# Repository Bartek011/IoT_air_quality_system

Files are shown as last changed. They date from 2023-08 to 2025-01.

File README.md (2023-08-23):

real

# Introduction
The aim of this thesis was to develop a system responsible for the control of air quality with particular emphasis on the measurement of concentrations of volatile organic compounds [VOC](https://www.epa.gov/indoor-air-quality-iaq/what-are-volatile-organic-compounds-vocs) and atmospheric particulate matter [PM](https://www.epa.gov/pm-pollution/particulate-matter-pm-basics).
System also provide measurment of temperature, humidity and atmospheric pressure. The data is available on the local server as measurment dashboard created in Grafana.
User can also receive notification about dangerour level of pollution via discord server

# Flow chart

real

# PCB

real

# Housing

real

# Grafana
Grafana was used to create dashbord with every available measurement data.

real
real
real

# Thesis
Thesis was published in polish on [Base of Knowledge Warsaw Univesity of Technology](https://repo.pw.edu.pl/info/bachelor/WUTc83da9b0bee349f29c8757139889ff39/Record%2Bdetails%2B%25E2%2580%2593%2BEngineer%2527s%2B%2B%2BBachelors%2Btheses%2B%25E2%2580%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) or you can download it directly from [here](https://drive.google.com/file/d/1R5NCyFZBSwMBP0MNRJKKGEtg320z7_zO/view?usp=drive_link).

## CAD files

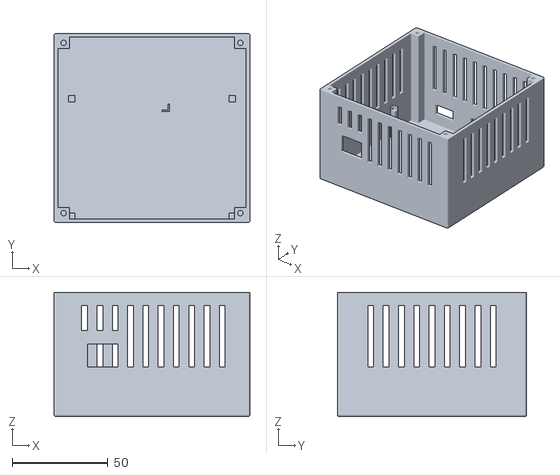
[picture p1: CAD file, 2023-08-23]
podstawa.stl
102.5 x 99.0 x 65.0

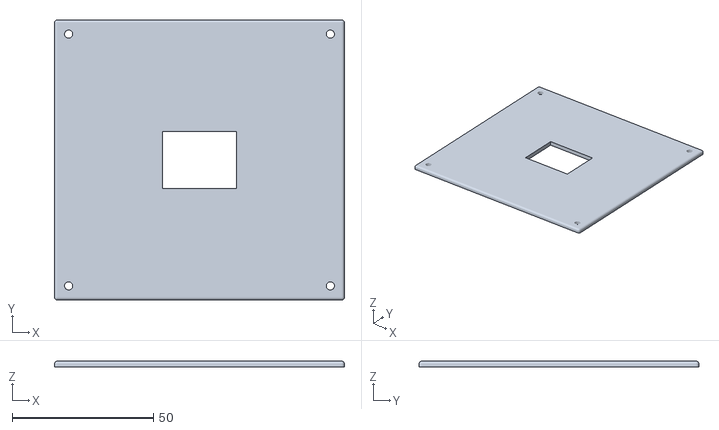
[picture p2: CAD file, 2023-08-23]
pokrywa.stl
102.5 x 99.0 x 2.00

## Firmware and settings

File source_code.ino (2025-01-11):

#include <Adafruit_Sensor.h>
#include <DHT_U.h>
#include <Wire.h>
#include <Adafruit_BMP280.h>
#include <DFRobot_SGP40.h>
#include <PMS.h>
#include <Animation.h>
#include <Adafruit_GFX.h>
#include <Adafruit_SSD1306.h>
#include <ESP8266WiFiMulti.h>
#include <InfluxDbClient.h>
#include <InfluxDbCloud.h>

#define SCREEN_WIDTH 128 // Szerokosc wyswiatlacza OLED
#define SCREEN_HEIGHT 64 // Wysokosc wyswietlacza OLED
#define OLED_RESET -1 // Pin do resetu wyswietlacza
#define SCREEN_ADRESS 0x3c // Adres wyswietlacza OLED
#define IMAGE_WIDTH 128 // Szerokosc wyswietlanych bitmap
#define IMAGE_HEIGHT 64 // Wysokosc wyswietlanych bitmap
#define X_START_POS 0 // Pozycja poczatkowa X kursora do wyswietlania bitmap
#define Y_START_POS 0 // Pozycja poczatkowa Y kursora do wyswietlania bitmap
#define DELAY_FRAMES 25 // Opoznienie miedzy klatkami animacji
#define ANIMATION_COLOR 1 // Kolor animowanych bitmap

#define DEVICE "ESP8266"

#define MILLIS_IN_DAY 86400000

#define WIFI_SSID "your_SSID" // WiFi AP SSID
#define WIFI_PASSWORD "your_PASSWORD" // WiFi password

#define INFLUXDB_URL "https://eu-central-1-1.aws.cloud2.influxdata.com"
#define INFLUXDB_TOKEN "your_TOKEN"
#define INFLUXDB_ORG "ffe702b83d51d588"
#define INFLUXDB_BUCKET "Temperatura"

#define TZ_INFO "UTC1" // Zdefiniowanie strefy czasowej dla Warszawy


ESP8266WiFiMulti wifiMulti;

InfluxDBClient client(INFLUXDB_URL, INFLUXDB_ORG, INFLUXDB_BUCKET, INFLUXDB_TOKEN, InfluxDbCloud2CACert); // Inicjalizacja klienta bazy InfluxDB

Adafruit_SSD1306 display(SCREEN_WIDTH, SCREEN_HEIGHT, &Wire, OLED_RESET); // Inicjalizacja wyswietlacza

Animation Animation(X_START_POS, Y_START_POS, SCREEN_WIDTH, SCREEN_HEIGHT, DELAY_FRAMES, ANIMATION_COLOR); // Inicjalizacja biblioteki animacji


PMS pms(Serial);
PMS::DATA data;

DHT_Unified dht(13, DHT11); //Inicjalizacjia pinu 13 do DHT11

Adafruit_BMP280 bme; // Inicjalizacja BMP280 I2C

DFRobot_SGP40    mySgp40; // Inicjalizacjia SGP40
bool starttime = false;
unsigned long czas_aktualny;
unsigned long czas_start;
bool firstRun = true;
bool avgPM = false;

unsigned int counter=0, cycles = 0;
float PM1 = 0, PM25 = 0, PM10 = 0;
float PM1set=0, PM25set=0, PM10set=0;
float PM25avg, PM10avg;
float PM25tab[900], PM10tab[900];
//Wspolczynniki do obliczen AQI
float PM25CLOW[8] = {0, 12.1, 35.5, 55.5, 150.5, 250.5, 350.5};
float PM25CHIGH[8] = {12, 35.4, 55.4, 150.4, 250.4, 350.4, 500.4};
float PM10CLOW[8] = {0, 55, 155, 255, 355, 425, 505};
float PM10CHIGH[8] = {54, 154, 254, 354, 424, 504, 604};
float AQIILOW[8] = {0, 51, 101, 151, 201, 301, 401};
float AQIIHIGH[8] = {50, 100, 150, 200, 300, 400, 500};
short AQI25set, AQI10set;
int AQIPM25, AQIPM10;

float temperatureBMP;
float humidityDHT;
float pressureBMP;
unsigned int vocSGP;
Point sensor("AirQuality");

void setup() {

    if(!display.begin(SSD1306_SWITCHCAPVCC, SCREEN_ADRESS)) {
    while(true); // Nieskonczona petla do oczekiwania
    display.display();
    display.clearDisplay();
    display.invertDisplay(true); // Inwersja wyswietlacza o 180°
  }
  
  display.setTextSize(3); // Domyslna wielkosc tekstu
  display.setTextColor(SSD1306_WHITE); // Domyslny kolor tekstu
  
  Serial.begin(9600); // Inicjalizacja portu szeregowego do debuggowania
  Animation.gear();
  while(mySgp40.begin(10000) != true){ // Oczekiwanie na skonfigurowanie polaczenia z SGP40
    Animation.sgp40Error(); // Wyświetlenie komunikatu o problemie z SGP40
    delay(1000);
  }
  
  dht.begin();
  sensor_t Sensor;
    
  if (!bme.begin()){
    Animation.bmp280Error(); // Wyświetlenie komunikatu o problemie z BMP280
    delay(1000);
  }
  
  Animation.gear();
  Animation.network();
  
  WiFi.mode(WIFI_STA);  //Inicjalizacja Wifi
  wifiMulti.addAP(WIFI_SSID, WIFI_PASSWORD);  //Logowanie do sieci WiFi

  while (wifiMulti.run() != WL_CONNECTED) // Oczekiwanie na nawiązanie połączenia
    delay(100);
  
  timeSync(TZ_INFO, "time.coi.pw.edu.pl"); //Synchronizacja czasu

  // Sprawdzenie polaczenia z baza danych
  if (client.validateConnection())
    Animation.connectionSuccess();  // Wyświetlenie komunikatu o poprawnym nawiązaniu połączenia z bazą InfluxDB
   else
    Animation.connectionFailed();  // Wyświetlenie komunikatu o błędzie przy nawiązaniu połączenia z bazą InfluxDB 
    
   sensor.addTag("device", DEVICE);

  pms.activeMode();    // PMS tryb aktywny

  Animation.network();
  
}

void loop() {
  
  display.clearDisplay();
  sensor.clearFields();

  // Pomiar temperatury.
  sensors_event_t event;
  Animation.temperature();
  temperatureBMP = bme.readTemperature();
  
  display.clearDisplay();
  display.setTextSize(3);
  display.setCursor(10,20);
  display.print(temperatureBMP,1);
  display.print((char)247);
  display.println("C");
  display.display();
  sensor.addField("tempBMP", temperatureBMP); //dodanie temperatury do bazy
  delay(7500);

  // Pomiar wilgotności
  Animation.humidity();
  dht.humidity().getEvent(&event);
  
  if (isnan(event.relative_humidity)){
     Animation.dht11Error();
    delay(1000);
  }
  else{
     humidityDHT = event.relative_humidity;
  }

  display.clearDisplay();
  display.setTextSize(5);
  display.setCursor(20,15);
  display.print(humidityDHT,0);
  display.println("%");
  display.display();
  sensor.addField("humDHT", humidityDHT); //dodanie wilgotnosci do bazy
  delay(7500);

  // Pomiar ciśnienia
  Animation.pressure();
  pressureBMP = (bme.readPressure()/100);
  display.setTextSize(3);
  display.clearDisplay();
  display.setCursor(0,20);
  display.print(pressureBMP, 0);
  display.println("hPa");
  display.display();
  
  sensor.addField("pressBMP", pressureBMP); //dodanie cisnienia do bazy
  delay(7500);

  //korekta LZO wzgledem wilgotnosci i temperatury
   mySgp40.setRhT(/*wilgotnosc = */ int(event.relative_humidity), /*temperatura = */ int(bme.readTemperature()));
  
   Animation.voc();
   vocSGP = mySgp40.getVoclndex();
   display.setTextSize(5);
   display.clearDisplay();

   if(vocSGP < 100){ // Wartość LZO jest dobra, wyświetl uśmiechniętą buźkę
    display.setCursor(32,16);
    display.print(vocSGP);
    display.display();
    delay(7500);
    Animation.smileface();
    Animation.smileface();
   }
   if(vocSGP >= 100){ // Wartość LZO jest dobra, wyświetl uśmiechniętą buźkę, wyśrodkowanie tekstu dla 3cyfrowej wartości
    display.setCursor(20,15);
    display.print(vocSGP);
    display.display();
    delay(5000);
    if (vocSGP <= 100){
      Animation.smileface();
      Animation.smileface();
    }
    else if (vocSGP > 100 && vocSGP <= 300){ // Wartość LZO w normie, wyświetl buźkę z neutralną minką 
      Animation.neutralface();
      Animation.neutralface();
    }
    else{ // Wartość LZO przekroczyła 300, zła jakość powietrza, wyświetl smutną buźkę
      Animation.sadface();
      Animation.sadface();
    }
    delay(3500);
   }
   
   display.setTextSize(3);
   sensor.addField("vocSGP40", vocSGP); //dodanie LZO do bazy
    
    pms.requestRead(); // Rozpocznij pomiar PM
    delay(1000);
    
    for(int i = 0; i < 20; i++){ // Usrednij 20 odczytow PM do jednego
      if(pms.readUntil(data)){
        PM1set += data.PM_AE_UG_1_0;
        PM25set += data.PM_AE_UG_2_5;
        PM10set += data.PM_AE_UG_10_0;
    }
    }

    // Oblicz usredniona wartosc z 20 pomiarow PM
    PM1 = PM1set/20;
    PM25 = PM25set/20;
    PM10 = PM10set/20;

    PM1set = 0;
    PM25set = 0;
    PM10set = 0;

    // Rozpocznij pomiar czasu dla wyliczenia indeksu AQI dla pierwszego cyklu
    if(firstRun){ 
      czas_start = millis();
      firstRun = false;
    }
    
   // Wpisanie wartości do tablicy    
    PM25tab[counter] = PM25;
    PM10tab[counter] = PM10;
    counter++;

    //Wybierz aktualną liczbe ukonczonych cykli, po 24h bez zmian
    cycles = max(counter, cycles);
    czas_aktualny = millis();
    if(((czas_aktualny - czas_start) > MILLIS_IN_DAY)  || avgPM){

      // Po 24h rozpocznij wypelnianie tablicy od poczatku
      if((czas_aktualny - czas_start) > MILLIS_IN_DAY){
        counter = 0;
        czas_start = millis();
      }

      // Flaga do wyświetlania AQI na OLED     
      avgPM = true;

      // Oblicz wartosc srednia stezenia PM
      for (int i = 0; i < cycles; i++){
      PM25avg += PM25tab[i];
      PM10avg += PM10tab[i];
    }
    PM25avg /= cycles;
    PM10avg /= cycles;
    
   // Przypisz odpowiednia flage w zaleznosci od stezenia PM2.5
   if(PM25avg <= 12)
    AQI25set = 0;
   if(PM25avg > 12 && PM25avg <= 35.4)
    AQI25set = 1;
   if(PM25avg > 35.4 && PM25avg <= 55.4)
    AQI25set = 2; 
   if(PM25avg > 55.4 && PM25avg <= 150.4)
    AQI25set = 3;
   if(PM25avg > 150.4 && PM25avg <= 250.4)
    AQI25set = 4;
   if(PM25avg > 250.4 && PM25avg <= 350.4)
    AQI25set = 5;
   if(PM25avg > 350.4)
    AQI25set = 6;
    
   // Oblicz wspolczynnik AQI dla PM2.5
   AQIPM25 = ((AQIIHIGH[AQI25set] - AQIILOW[AQI25set])/(PM25CHIGH[AQI25set] - PM25CLOW[AQI25set]))*(PM25avg - PM25CLOW[AQI25set])+AQIILOW[AQI25set];

  // Przypisz odpowiednia flage w zaleznosci od stezenia PM10
   if(PM10avg <= 54)
    AQI10set = 0;
   if(PM10avg > 54 && PM10avg <= 154)
    AQI10set = 1;
   if(PM10avg > 154 && PM10avg <= 254)
    AQI10set = 2; 
   if(PM10avg > 254 && PM10avg <=354)
    AQI10set = 3;
   if(PM10avg > 354 && PM10avg <= 424)
    AQI10set = 4;
   if(PM10avg > 424 && PM10avg <= 504)
    AQI10set = 5;
   if(PM25avg > 504)
    AQI10set = 6;

   // Oblicz wspolczynnik AQI dla PM2.5  
   AQIPM10 = ((AQIIHIGH[AQI10set] - AQIILOW[AQI10set])/(PM10CHIGH[AQI10set] - PM10CLOW[AQI10set]))*(PM10avg - PM10CLOW[AQI10set])+AQIILOW[AQI10set];

   PM25avg = 0;
   PM10avg = 0;
    }

   Animation.pm();
   delay(1000);
  
   display.clearDisplay();
   display.setTextSize(3);
   display.setCursor(30, 2);
   display.println(PM1,1);
   display.setTextSize(2);
   display.setCursor(48,50);
   display.print("PM1");
   display.display();
   delay(6000);
  //Dodanie PM1 do bazy
   sensor.addField("pm1", PM1);

   Animation.pm();
   delay(1000);
   display.clearDisplay();
   display.setTextSize(3);
   display.setCursor(30, 2);
   display.println(PM25,1);
   display.setTextSize(2);
   display.setCursor(40,50);
   display.print("PM2,5");
   display.display();
   delay(3000);
   //Dodanie PM2.5 od bazy
   sensor.addField("pm2.5", PM25);
   if(avgPM){
    display.clearDisplay();
    display.setTextSize(4);
    display.setCursor(27, 20);
    display.println("AQI");
    display.display();
    delay(1500);
    display.clearDisplay();
    display.setTextSize(5);
    display.setCursor(20,15);
    display.println(AQIPM25);
    display.display();
    delay(2500); 
    if(AQIPM25<51){
      Animation.smileface();
      Animation.smileface();
    }
    else if(AQIPM25 >= 51 && AQIPM25 < 151){
      Animation.neutralface();
      Animation.neutralface();
    }
    else if(AQIPM25 >= 151){
      Animation.sadface();
      Animation.sadface();
    }
    delay(3500); 
    }
    else{
      delay(9500);
    }

   Animation.pm();
   delay(1000);
   //Dodanie PM10 do bazy
   sensor.addField("pm10", PM10);

   display.clearDisplay();
   display.setTextSize(3);
   display.setCursor(30, 2);
   display.println(PM10,1);
   display.setTextSize(2);
   display.setCursor(40,50);
   display.print("PM10");
   display.display();
   delay(3000);
    if(avgPM){
    display.clearDisplay();
    display.setTextSize(4);
    display.setCursor(27, 20);
    display.println("AQI");
    display.display();
    delay(1500);
    display.clearDisplay();
    display.setTextSize(5);
    display.setCursor(20,15);
    display.println(AQIPM10);
    display.display();
    delay(2500);
    if(AQIPM10<51){
      Animation.smileface();
      Animation.smileface();
    }
    else if(AQIPM10 >= 51 && AQIPM10 < 151){
      Animation.neutralface();
      Animation.neutralface();
    }
    else if(AQIPM10 >= 151){
      Animation.sadface();
      Animation.sadface();
    }
    delay(3500);      
   }
   else{
    delay(9500);
   }
   sensor.addField("pm10", PM10);

   //Wyslij wszystkie wartosc do bazy InfluxDB
   sensor.toLineProtocol();
   client.writePoint(sensor);

   //Sprawdz WiFi i ponownie polacz w razie potrzeby
   if (wifiMulti.run() != WL_CONNECTED) {
      Animation.connectionFailed();
   }
   //Błąd network timeout
    if (!client.writePoint(sensor)) {
      Animation.influxDBError();  //Wyświetlenie komunikatu o problemie z zapisem do bazy InfluxDB 

    }
   

}

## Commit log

2023-08-23 Final version
    [Drill_PTH_Through.DRL, Drill_PTH_Through_Via.DRL, Gerber_BoardOutlineLayer.GKO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]
2025-01-11 Update source_code.ino
    Fix NTC
    [source_code.ino]
